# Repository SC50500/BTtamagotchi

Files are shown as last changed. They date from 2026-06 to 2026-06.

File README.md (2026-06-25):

# ARIRANG
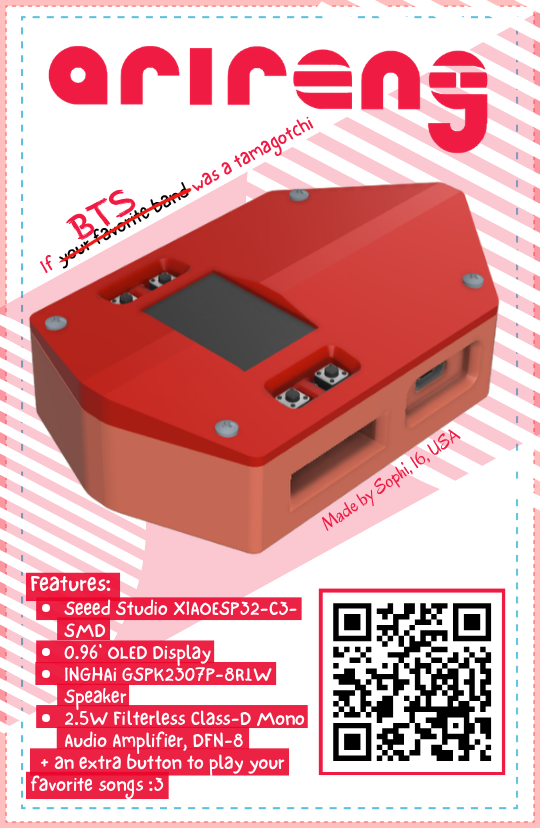
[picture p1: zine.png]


# Description
A 4-button tamagotchi remix based on global pop band BTS's new album "ARIRANG" featuring a speaker in place of a buzzer and unique tamagotchi dancing emoticons. Instead of indicating changes in the pet's state using buzzes, the ARIRANG tamagotchi uses a sequence of notes from the speaker to play a familiar tune. What makes this tamagotchi design unique is that it uses easily accessible parts and produces sound from the speaker without storage of music on a micro-SD card or similar component. Music is played through using the tone() function in the Arduino IDE. 

# Purpose
The basic eat, sleep, and play functions of your average tamagotchi are still present in this design, allowing users to interact with their tamagotchi pet at any time of day. An additional music feature has been added to the tamagotchi, as coded for by the fourth button on the PCB. This button plays one of three tunes, extrapolated from popular BTS songs and inspired by piano or music box covers arranged by other composers and artists (View credits for more information). 

For more information about what a tamagotchi is and how to use it, check out [this guide](https://tamagotchi.fandom.com/wiki/Main_Page) on what a tamagotchi is. 

# Inspiration
As someone who has been a fan of BTS since they were 7 years old, I've dreamed of completing a project that allowed me to take creative liberty in designing a product that reflected both my interest in KPOP and engineering.
The theme of the tamagotchi was centered around "ARIRANG", BTS's newest album that was recently released this year. After being inactive as a band for over 3 years, this was the long-awaited "comeback" album that myself and other long-time fans were excited to listen to.
More importantly, this album holds a different meaning to the fandom, ARMY, and the group; It is meant to represent a return to the roots from which BTS first came.
So, in honor of their return from their hiatus, I decided to dedicate my first hardware project to them -- A band whose songs motivated me throughout all of the obstacles I overcame to ship this project. 

# Features
* **0.96" OLED Display (128 x 64):** Black and white, yes, but perfect for Van, a character that is monochromatic ;3
* **INGHAi Speaker:** A small, but powerful speaker with a simple adapter that allows for music from Arduino IDE or bluetooth to be played. 
* **Four tactile switches:** The first three are for the basic eat, sleep, and play functions of the tamagotchi, but the fourth is a "music" button that activates one of three tunes that any BTS fan would recognize, paired with a pet dancing animation.
* **Unique themed pet and animations:** Your tamagotchi pet goes by the name Van! Van is a character from the LINE x BTS collaboration, which produced a line of BTS mascots called BT21. In this collaboration, Van represents the ARMY, BTS's fandom, instead of a specific member. I felt that because of this, Van was the most suitable mascot for this project. 

# How does this work? 
Each of the four different buttons are mapped to one of four screens: eat, play, sleep, and dance/music.

* Left-up button: For when Van is feeling a bit peckish
* Left-down button: For when Van is bored
* Right-up button: For when Van needs some rest
* Right-down button: For when Van is ready to party :3

When these buttons are pressed, a quick transition music is played to indicate a change in Van's status. If any of Van's status bars (Hunger, Happiness, and Energy) fall below 50, Van's expression will change into a sad expression. 

After each animation runs its course, the screen returns back to the main screen while the pet awaits further instruction.

# Design
Below are all of the screenshots of my design (plus screenshots by layer and an exploded view :3)










# Bill of Materials

| Item | Unit Price | Quantity Used | Quantity Purchased | Total Price | Source | Notes |
|---|---|---|---|---|---|---|
| Seeed Studio XIAO ESP32-C3 | $9.90 | 1 | 1 | $9.90 | [Link](https://www.amazon.com/dp/B0B94JZ2YF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) | purchased with other items off Amazon; free shipping |
| HS96L03W2C03 | $2.24 | 1 | 1 | $2.24 | [Link](https://www.lcsc.com/product-detail/C5248080.html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) | shipping not included |
| INGHAi GSPK2307P-8R1W | $0.82 | 1 | 1 | $0.82 | [Link](https://www.lcsc.com/product-detail/Speakers_INGHAi-GSPK2307P-8R1W_C530531.html) | shipping not included |
| PAM8302AAYCR | $9.37 | 1 | 1 | $9.37 | [Link](https://www.digikey.com/en/products/detail/diodes-incorporated/PAM8302AAYCR/4033367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) | shipping included |
| BZCN TSC016A04518A | $0.04 | 4 | 50 | $0.54 | [Link](https://www.lcsc.com/product-detail/C2888493.html?s_z=h_q_C2888493&globalKeyword=C2888493) | shipping not included |
| UNIT 502030 D9 - 250mAh 3.7V 0.93Wh | $8.99 | 1 | 1 | $8.99 | [Link](https://www.amazon.com/dp/B08FD3V6TF?lv=shuf&channelId=520&plpRedirect=mhFallback) | shipping not included |
| TAMAGOTCHI PCB | $2.00 | 1 | 5 | $2.00 | [Link](https://cart.jlcpcb.com/shopcart/cart/) | first PCB is $2.00; no shipping fee or taxes (Global standard line) |
| M3 x 8mm Pozi Pan Head Screws | $0.09 | 2 | 20 | $0.99 | [Link](https://www.aliexpress.us/item/3256807955659503.html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) | not 1:1 to the attached CAD; but can still be used; shipping not included |
| M2 x 8mm Pozi Pan Head Screws | $0.20 | 4 | 20 | $0.99 | [Link](https://www.aliexpress.us/item/3256807955659503.html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) | not 1:1 to the attached CAD; but can still be used; shipping not included |
| *AMAZON SHIPPING & TAXES* |  |  |  | *$9.29* |  | ONLY shipping fees and taxes for all products purchased through Amazon |
| *LCSC SHIPPING & TAXES* |  |  |  | *$10.65* |  | ONLY shipping fees and taxes for all products purchased through LCSC |
| *ALIEXPRESS SHIPPING & TAXES* |  |  |  | *$4.09* |  | ONLY shipping fees and taxes for all products purchased through AliExpress |
| **TOTAL** |  |  |  | **$53.80** |  |  |

# Build & Assembly

## Required Tools

- Soldering iron
- Solder
- Tweezers
- Small screwdriver for M3 screws
- Computer with USB port
- 3D printer

## Assembly Steps

1. Solder all the THT diodes onto the PCB
2. Solder the LEDs to the PCB. I rotated the direction of the bottom row by accident so refer to the PCB layout if the orientation is confusing at all
3. Solder the microcontroller, OLED display, and switches to the PCB
4. To assemble the case, place the PCB into the bottom shell
5. Attach it to the top shell
6. Secure with M3 screws.
7. Since this build uses the ESP32-C3, I will use the ESPRESSIF Arduino IDE Extension to install firmware
8. Plug in the ESP32-C3 to your computer with a USB cable
9. Select the correct board and port in the Arduino IDE, then upload the firmware
10. Modify the code if you'd like to change Van's animations or tune selection
11. Test your OLED (check I2C, SDA/SCL pins, etc) and your speaker
12. Once everything works, you will have a fully functional Van!

# Credits & Acknowledgements

Credits to BTS's new "ARIRANG" album cover and the BTS ARMY Logo for the hardware design inspiration. 

## Libraries & Extensions Used

Libraries and extensions used in firmware
* ESPRESSIF Arduino IDE Extension
* Adafruit SSD1306
* Adafruit GFX Library

## Music Attribution & Copyright Disclaimer
The audio files included in this repository are piano covers intended for non-commercial entertainment purposes only.

*    *Original Composition:* "Crystal Snow", "Spring Day", and "Butterfly", intitially performed by BTS, copyrighted by Big Hit Music / HYBE. 
*    *Arrangements:* Based on the piano arrangements by [SMYANG PIANO](https://www.youtube.com/c/smyangpiano) (used with pending permission.
*    *Performances:* Recorded and arranged by Sophia Chan.

*Disclaimer: Although the music used in the tamagotchi are inspired by the music box and piano arrangements created by SMYANG PIANO as a cover for BTS's music, the actual arrangements slightly differ in composition.*

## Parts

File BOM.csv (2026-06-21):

Item | Unit Price | Quantity Used | Quantity Purchased | Total Price | Source | Notes
Seeed Studio XIAO ESP32-C3 | $9.90 | 1 | 1 | $9.90 | https://www.amazon.com/dp/B0B94JZ2YF?lv=shuf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 | purchased with other items off Amazon; free shipping
HS96L03W2C03 | $2.24 | 1 | 1 | $2.24 | https://www.lcsc.com/product-detail/C5248080.html | shipping not included
INGHAi GSPK2307P-8R1W | $0.82 | 1 | 1 | $0.82 | https://www.lcsc.com/product-detail/Speakers_INGHAi-GSPK2307P-8R1W_C530531.html | shipping not included
PAM8302AAYCR | $9.37 | 1 | 1 | $9.37 | https://www.digikey.com/en/products/detail/diodes-incorporated/PAM8302AAYCR/4033367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 | shipping included
BZCN TSC016A04518A | $0.04 | 4 | 50 | $0.54 | https://www.lcsc.com/product-detail/C2888493.html?s_z=h_q_C2888493&globalKeyword=C2888493 | shipping not included
UNIT 502030 D9 - 250mAh 3.7V 0.93Wh | $8.99 | 1 | 1 | $8.99 | https://www.amazon.com/dp/B08FD3V6TF?lv=shuf&channelId=520&plpRedirect=mhFallback | shipping not included
TAMAGOTCHI PCB | $2.00 | 1 | 5 | $2.00 | https://cart.jlcpcb.com/shopcart/cart/ | first PCB is $2.00; no shipping fee or taxes (Global standard line)
M3 x 8mm Pozi Pan Head Screws | $0.09 | 2 | 20 | $0.99 | https://www.aliexpress.us/item/3256807955659503.html?curPageLogUid=W6HOdQGM0dw9 | not 1:1 to the attached CAD; but can still be used; shipping not included
M2 x 8mm Pozi Pan Head Screws | $0.20 | 4 | 20 | $0.99 | https://www.aliexpress.us/item/3256807955659503.html?curPageLogUid=W6HOdQGM0dw9 | not 1:1 to the attached CAD; but can still be used; shipping not included
AMAZON SHIPPING & TAXES |  |  |  | $9.29 |  | ONLY shipping fees and taxes for all products purchased through Amazon
LCSC SHIPPING & TAXES |  |  |  | $10.65 |  | ONLY shipping fees and taxes for all products purchased through LCSC
ALIEXPRESS SHIPPING $ TAXES |  |  |  | $4.09 |  | ONLY shipping fees and taxes for all products purchased through AliExpress
TOTAL |  |  |  | $59.87

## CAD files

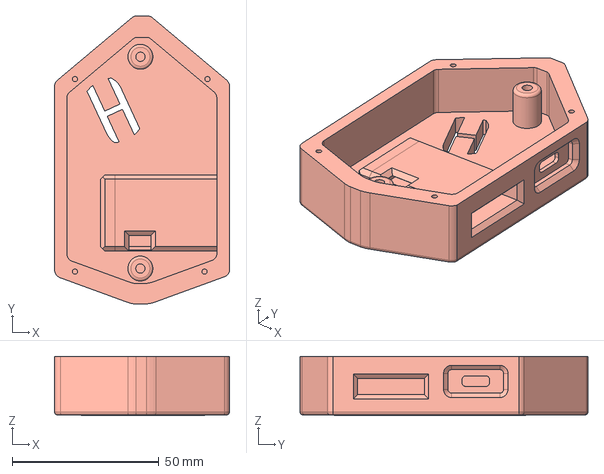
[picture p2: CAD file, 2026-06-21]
case/CAD files/Top.step
59.7 x 98.2 x 20.3 mm

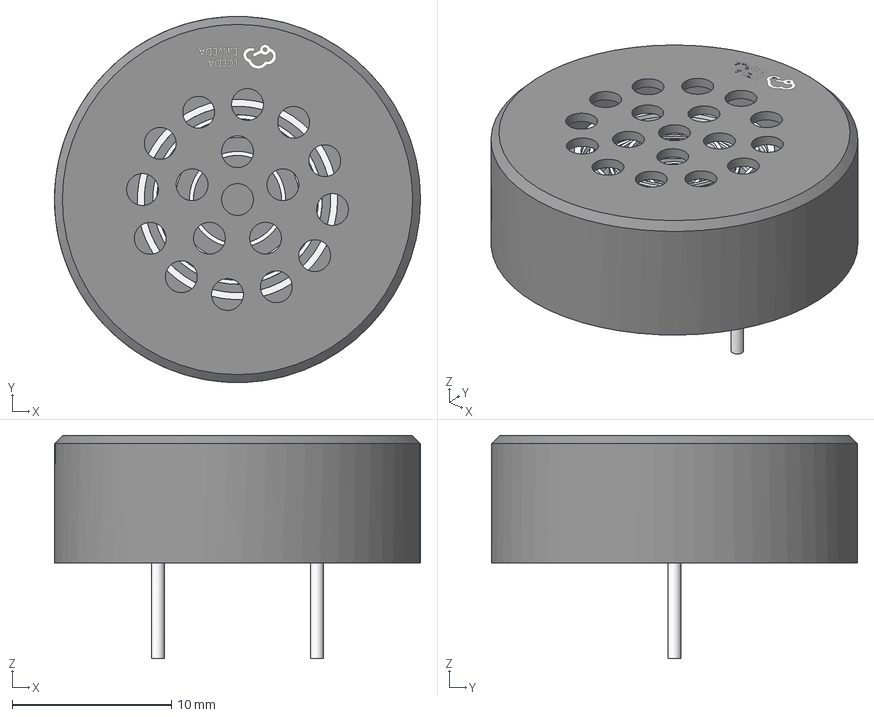
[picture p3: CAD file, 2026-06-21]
case/CAD models/SPK-TH_BD23.0-P10.00-D0.8-L-RD.step
23.0 x 23.0 x 14.0 mm
SPK-TH_BD2 x 21

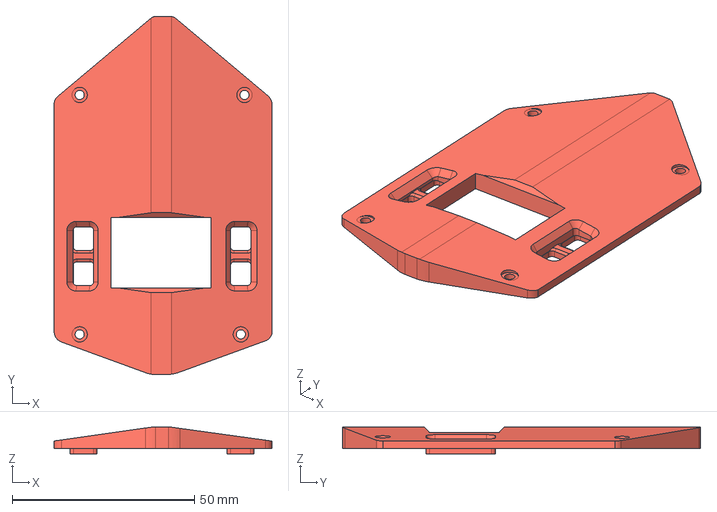
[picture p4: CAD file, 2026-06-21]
case/CAD files/Bottom.step
59.7 x 98.1 x 7.30 mm

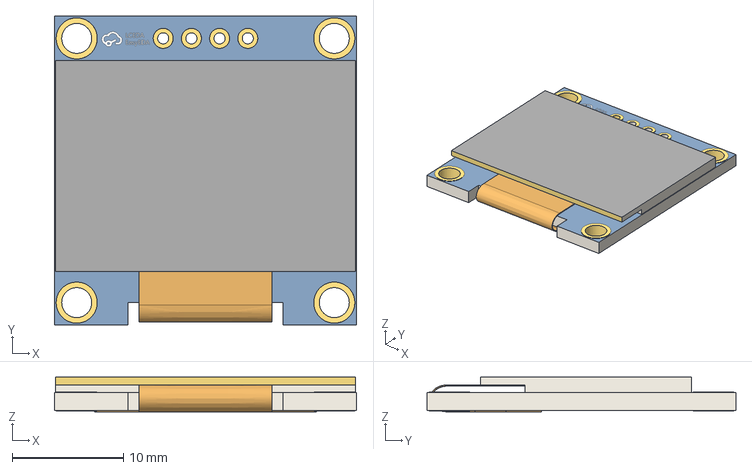
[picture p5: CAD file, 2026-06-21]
case/CAD models/OLED-TH_L27.8-W27.2-P2.54_C9900033791.step
27.2 x 27.8 x 3.12 mm

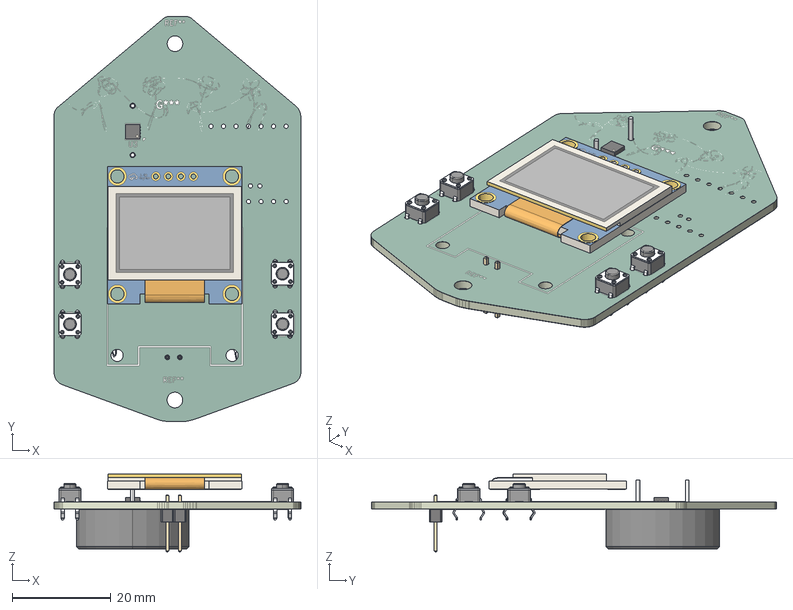
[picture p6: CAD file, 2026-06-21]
case/CAD files/ARIRANG.step
50.0 x 82.0 x 15.7 mm
DFN-8-1EP_3x3mm_Pitch0.65mm
OLED-TH_L27.8-W27.2-P2.54_C9900033791
PinHeader_1x02_P254mm_Vertical
SPK-TH_BD2
BTtamagotchi_copper
BTtamagotchi_via
BTtamagotchi_silkscreen x 2
BTtamagotchi_soldermask x 2
BTtamagotchi_PCB

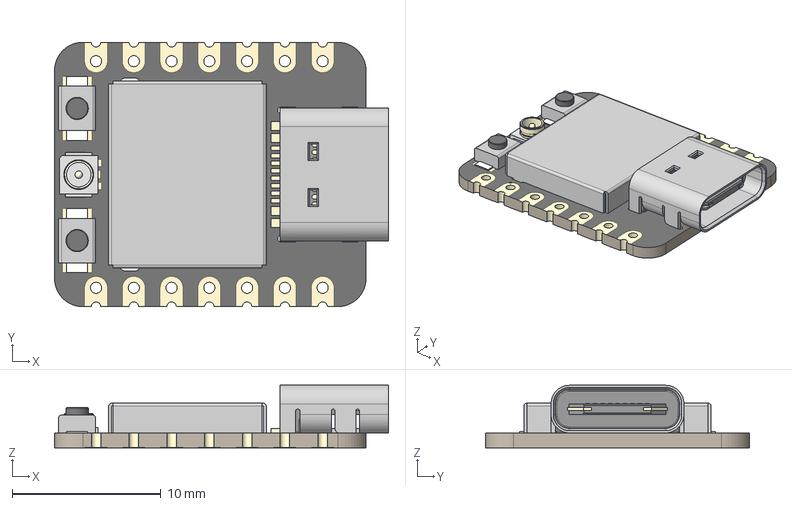
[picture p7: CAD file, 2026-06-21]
case/CAD models/Seeed Studio XIAO-ESP32-C3 v15.step
22.5 x 17.8 x 4.21 mm
U.FL Connector v1 x 3
Shield
Button (1) x 2
Seeed Studio XIAO-ESP32-C3 v15
MIRROR2
BOSS-EXTRUDE7_3_
BOSS-EXTRUDE14_9_
BOSS-EXTRUDE7_9_
CUT-EXTRUDE5
BOSS-EXTRUDE14_6_
BOSS-EXTRUDE14_4_
BOSS-EXTRUDE7_1_
BOSS-EXTRUDE14_5_
BOSS-EXTRUDE14_10_
BOSS-EXTRUDE14_11_
BOSS-EXTRUDE7_8_
BOSS-EXTRUDE14_1_
BOSS-EXTRUDE14_8_
BOSS-EXTRUDE7_6_
BOSS-EXTRUDE7_4_
BOSS-EXTRUDE7_7_
BOSS-EXTRUDE14_7_
BOSS-EXTRUDE14_12_
BOSS-EXTRUDE14_3_
BOSS-EXTRUDE7_2_
BOSS-EXTRUDE14_2_
BOSS-EXTRUDE7_5_

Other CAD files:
case/CAD files/ARIRANG FINAL.f3d
case/CAD files/Bottom.stl
case/CAD files/Top.stl

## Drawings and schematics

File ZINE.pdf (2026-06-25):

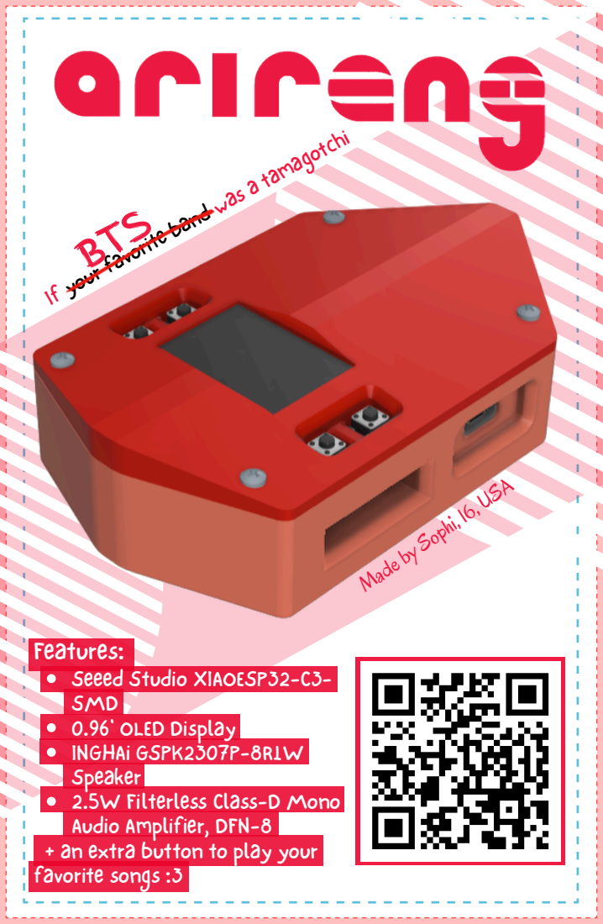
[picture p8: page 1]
BTS; Features:; 0.96' OLED Display INGHAi GSPK2307P-8R1W; USA

If your favorite band was a tamagotchi

Made by Sophi,

Seeed Studio XIAOESP32-C3-
SMD
Speaker
2.5W Filterless Class-D Mono
Audio Amplifier, DFN-8

+ an extra button to play your
favorite songs :3

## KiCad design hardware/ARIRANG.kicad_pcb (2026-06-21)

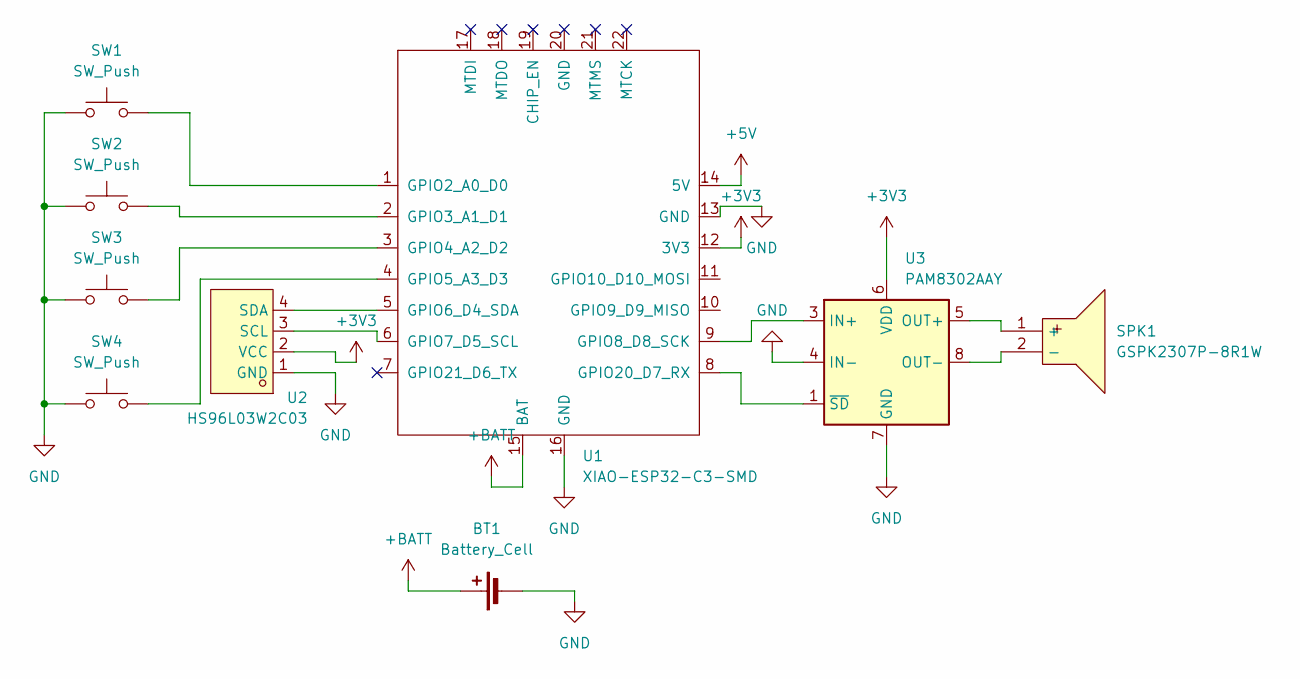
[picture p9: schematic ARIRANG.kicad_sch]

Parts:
BT1: Battery_Cell; PinHeader_1x02_P2.54mm_Vertical
SPK1: GSPK2307P-8R1W; SPK-TH_BD23.0-P10.00-D0.8-L-RD; MPN GSPK2307P-8R1W; LCSC Part C530531
SW1, SW2, SW3, SW4: SW_Push; SW-TH_4P-L4.5-W4.5-P3.00-LS4.8
U1: XIAO-ESP32-C3-SMD; XIAO-ESP32-C3-DIP-SMD
U2: HS96L03W2C03; OLED-TH_L27.8-W27.2-P2.54_C9900033791; MPN HS96L03W2C03; LCSC Part C5248080
U3: PAM8302AAY; DFN-8-1EP_3x3mm_P0.65mm_EP1.55x2.4mm

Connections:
+3V3: U1.12 (3V3), U2.2 (VCC), U3.6 (VDD)
+5V: U1.14 (5V)
+BATT: BT1.1 (+), U1.15 (BAT)
GND: BT1.2 (-), SW1.1, SW2.1, SW3.1, SW4.1, U1.13 (GND), U1.16 (GND), U2.1 (GND), U3.4 (IN-), U3.7 (GND)
unnamed: SPK1.1 (+), U3.5 (OUT+)
unnamed: SPK1.2 (-), U3.8 (OUT-)
unnamed: SW1.2, U1.1 (GPIO2_A0_D0)
unnamed: SW2.2, U1.2 (GPIO3_A1_D1)
unnamed: SW3.2, U1.3 (GPIO4_A2_D2)
unnamed: SW4.2, U1.4 (GPIO5_A3_D3)
unnamed: U1.5 (GPIO6_D4_SDA), U2.4 (SDA)
unnamed: U1.6 (GPIO7_D5_SCL), U2.3 (SCL)
unnamed: U1.9 (GPIO8_D8_SCK), U3.3 (IN+)
unnamed: U1.8 (GPIO20_D7_RX), U3.1 (~SD)

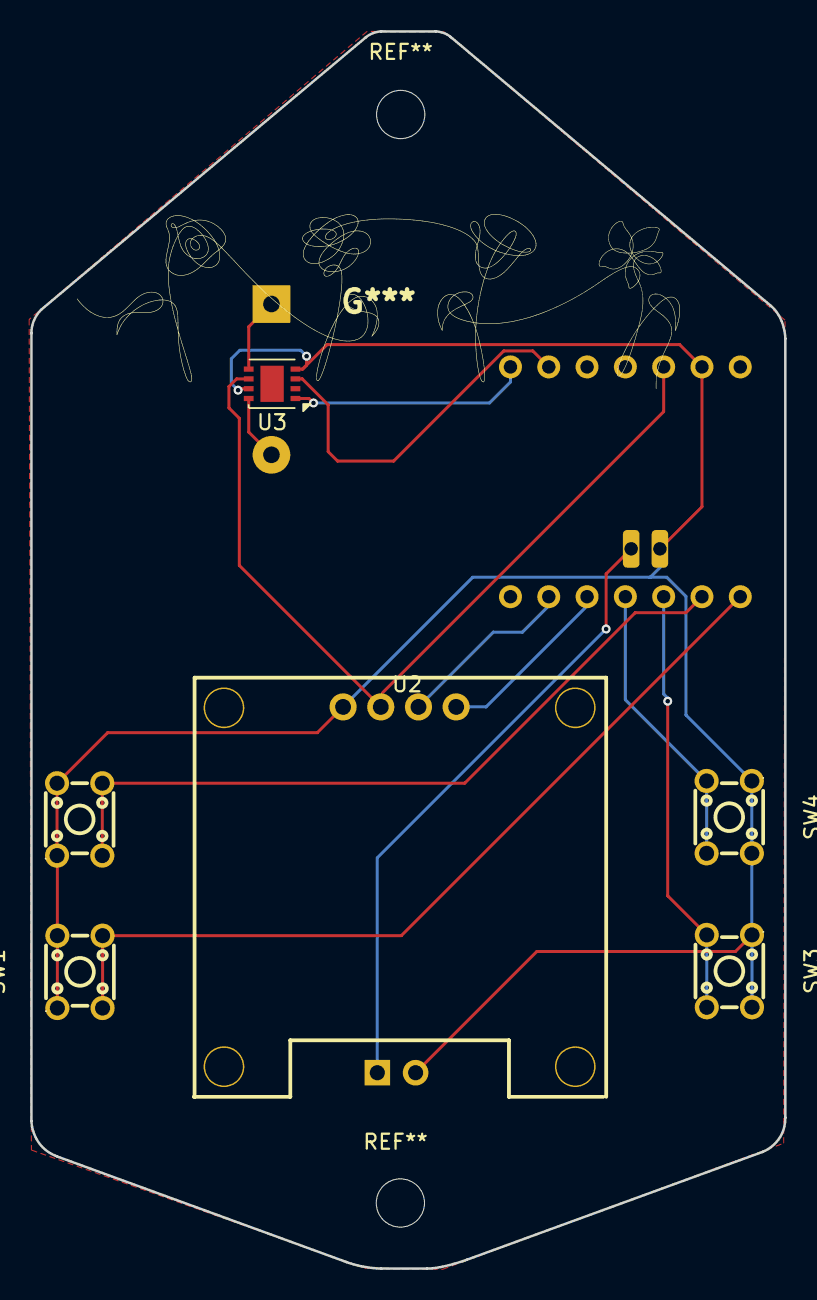
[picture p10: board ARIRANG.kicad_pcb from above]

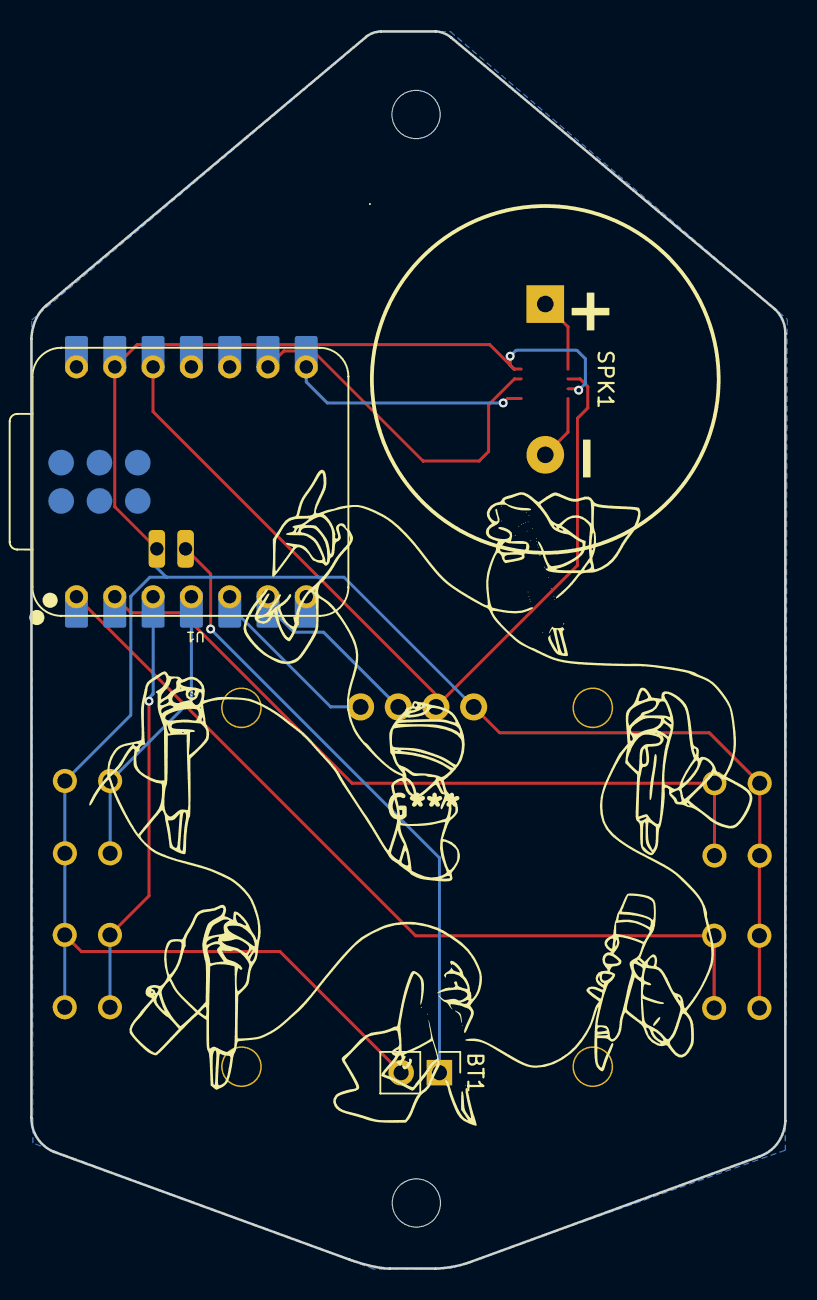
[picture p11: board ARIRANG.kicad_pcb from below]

Board: 2 copper layers, 50.0 x 82.0 mm, 9 parts (3 on the bottom side), 13 nets.

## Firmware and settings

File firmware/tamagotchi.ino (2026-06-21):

//Buttons (traced from schematic)
#define BTN1 0
#define BTN2 1
#define BTN3 2
#define BTN4 3
//OLED (traced from schematic)
#define SDA_PIN 5
#define SCL_PIN 6
//Speaker (traced from schematic)
#define SD_PIN 20
#define IN_PIN 8

#include <Wire.h>
#include <Adafruit_GFX.h>
#include <Adafruit_SSD1306.h>

#define SCREEN_WIDTH 128
#define SCREEN_HEIGHT 64
#define OLED_RESET -1

Adafruit_SSD1306 display(SCREEN_WIDTH, SCREEN_HEIGHT, &Wire, OLED_RESET);

#define BTN_LEFTUP   D0
#define BTN_LEFTDWN  D1
#define BTN_RIGHTUP  D2
#define BTN_RIGHTDWN D3
#define SPK_SD D7
#define SPK_IN D8

struct Member {
  int hunger;
  int happiness;
  int energy;
  unsigned long age;
}

Member Jimin;

enum Screen{
  SCREEN_MAIN,
  SCREEN_FEED,
  SCREEN_PLAY,
  SCREEN_SLEEP,
  SCREEN_MUSIC,
}

#define b3f 233 // 233 Hz
#define b3  247 // 247 Hz
#define e4f 311 // 311 Hz
#define g4  392 // 392 Hz
#define b4f 466 // 466 Hz
#define b4  493 // 493 Hz
#define c5s 554 // 554 Hz
#define d5  587 // 587 Hz
#define e5f 622 // 622 Hz
#define f5  698 // 698 Hz
#define g5  784 // 784 Hz
#define a5f 831 // 831 Hz
#define b5f 932 // 932 Hz

#define BUZZER_PIN 8  // change to match your wiring

// ---------- Garage_Band.mp3 ----------
const int GarageBand_notes[] = {
  b4f, a5f, g5, g4, g5, g4, g4, g4, g4, g4, f5, f5, g5, b4f, g5, g4, g4, g4,
  g4, g4, f5, f5, g5, g4, g4, g4, e5f, e4f, f5, d5, d5, b4f, b4f, b3f, d5,
  e5f, f5, f5, e5f, e4f, b4, b4, b4, b4f, b3f
};
const int GarageBand_durations[] = {
  615, 708, 789, 499, 708, 627, 372, 337, 290, 337, 372, 627, 1556, 279, 372,
  627, 337, 372, 290, 337, 372, 1126, 337, 372, 290, 383, 325, 964, 372, 1126,
  383, 337, 325, 337, 325, 998, 337, 998, 337, 1010, 325, 998, 337, 1115, 343
};
const int GarageBand_length = sizeof(GarageBand_notes) / sizeof(GarageBand_notes[0]);

// ---------- butterfly.mp3 ----------
const int Butterfly_notes[] = {
  c5s, c5s, e5f, e5f, e5f, e5f, e5f, e5f, c5s, c5s, e5f, e5f, e5f, c5s, c5s,
  e5f, e5f, e5f, e5f, e5f, e5f, c5s, f5, e5f, e5f, f5, e5f, e5f, e5f, c5s,
  e5f, c5s, f5, c5s, c5s, b5f
};
const int Butterfly_durations[] = {
  313, 313, 313, 325, 313, 313, 313, 313, 325, 859, 313, 313, 720, 313, 313,
  325, 313, 313, 313, 313, 325, 313, 313, 1498, 708, 325, 1254, 1428, 313,
  313, 313, 325, 627, 313, 313, 1489
};
const int Butterfly_length = sizeof(Butterfly_notes) / sizeof(Butterfly_notes[0]);

// ---------- crystal_snow.mp3 ----------
const int CrystalSnow_notes[] = {
  e5f, b5f, e5f, d5, b5f, b4f, e5f, b5f, f5, b5f, f5, g5, b5f, g5, g5, b4f,
  e5f, b5f, e5f, d5, b5f, b4f, e5f, b5f, f5, b4f, f5, g5, b5f, g5, b5f, b5f,
  b5f
};
const int CrystalSnow_durations[] = {
  325, 313, 313, 325, 313, 313, 313, 325, 313, 313, 313, 313, 325, 313, 313,
  313, 313, 325, 313, 313, 313, 313, 313, 325, 313, 313, 313, 313, 325, 313,
  859, 313, 305
};
const int CrystalSnow_length = sizeof(CrystalSnow_notes) / sizeof(CrystalSnow_notes[0]);

// Playback helper
void playMelody(const int notes[], const int durations[], int length) {
  for (int i = 0; i < length; i++) {
    int noteDuration = durations[i];
    tone(BUZZER_PIN, notes[i], noteDuration);
    // pause between notes ~10% of the note's length, for separation
    int pauseBetween = noteDuration * 1.10;
    delay(pauseBetween);
    noTone(BUZZER_PIN);
  }
}

// Named functions, one per source file
void playGarageBand() {
  playMelody(GarageBand_notes, GarageBand_durations, GarageBand_length);
}

void playButterfly() {
  playMelody(Butterfly_notes, Butterfly_durations, Butterfly_length);
}

void playCrystalSnow() {
  playMelody(CrystalSnow_notes, CrystalSnow_durations, CrystalSnow_length);
}

Screen currentScreen = SCREEN_MAIN;

void setup() {
  // put your setup code here, to run once:
  pinMode(BTN_LEFTUP, INPUT_PULLUP);
  pinMode(BTN_LEFTDWN, INPUT_PULLUP);
  pinMode(BTN_RIGHTUP, INPUT_PULLUP);
  pinMode(BTN_RIGHTUP, INPUT_PULLUP);
  pinMode(SPK_SD, INPUT_PULLUP);
  pinMode(SPK_IN, OUTPUT);

  display.begin(SSD1306_SWITCHCAPVCC, 0x3C);
  display.clearDisplay();
  display.setTextSize(1);
  display.setTextColor(SSD1306_WHITE);
  display.setCursor(0,0);
  display.println("Tamagotchi Init...");
  display.display();
  delay(1000);

  member.hunger = 80;
  member.happiness = 80;
  member.energy = 80;
  member.age = 0;
}

unsigned long lastUpdate = 0;

void updatePet(){
  if(millis() - lastUpdate > 5000){
    pet.hunger--;
    pet.happiness--;
    pet.energy--;
    
    if(pet.hunger < 0) pet.hunger = 0;
    if(pet.happiness < 0) pet.happiness = 0;
    if(pet.energy < 0) pet.energy = 0;
    
    pet.age +=== 5;
    lastUpdate = millis();
  }
}

unsigned long lastButtonPress = 0;
int 

void checkButtons(){
  if(millis() - lastButtonPress < 200) return;
  
  if(digitalRead(BTN_LEFTUP) == LOW){
    currentScreen = SCREEN_FEED;
    tone(SPK_IN, 1000, 50);
    lastButtonPress = millis();
  }
  else if(digitalRead(BTN_LEFTDWN) == LOW){
    currentScreen = SCREEN_PLAY;
    tone(SPK_IN, 1000, 50);
    lastButtonPress = millis();
  }
  else if(digitalRead(BTN_RIGHTUP) == LOW){
    currentScreen = SCREEN_SLEEP;
    tone(SPK_IN, 1000, 50);
    lastButtonPress = millis();
  }
  else(digitalRead(BTN_RIGHTDWN) == LOW){
    currentScreen = SCREEN_MUSIC;
    tone(SPK_IN, 1000, 50);
    lastButtonPress = millis();
  }
}

void handleScreenLogic(){
  switch(currentScreen){
    case SCREEN_FEED:
      pet.hunger += 10;
      if(pet.hunger > 100) pet.hunger = 100;
      currentScreen = SCREEN_MAIN;
      break;
    
    case SCREEN_PLAY:
      pet.happiness += 10;
      pet.energy -= 5;
      if(pet.happiness > 100) pet.happiness = 100;
      if(pet.energy < 0) pet.energy = 0;
      currentScreen = SCREEN_MAIN;
      break;

    case SCREEN_SLEEP:
      pet.energy += 5;
      if(pet.energy > 100) pet.energy = 100;
      currentScreen = SCREEN_MAIN;
      break;

    case SCREEN_MUSIC:
      pet.happiness += 5;
      pet.energy -= 2;
      if(pet.happiness > 100) pet.happiness = 100;
      if(pet.energy < 0) pet.energy = 0;
      currentScreen = SCREEN_MAIN;
      playGarageBand();
      playButterfly();
      playCrystalSnow();
      break;
    
    case SCREEN_MAIN:
      break;
  }
}

#include <Arduino.h>

const unsigned char PROGMEM frame0[] = {
  0b00000000, 0b00000000, 0b00000000, 0b00000000, 0b00000000, 0b00000000, 0b00000000, 0b00000000, 0b00000000, 0b00000000,
  0b00000000, 0b00000000, 0b00000011, 0b11000000, 0b00000000, 0b00000000, 0b00000000, 0b00000000, 0b00000000, 0b00000000,
  0b00000000, 0b00000000, 0b00000010, 0b01000000, 0b00000000, 0b00000000, 0b00000000, 0b00000000, 0b00000000, 0b00000000,
  0b00000000, 0b00000000, 0b00000110, 0b10100000, 0b00000000, 0b00000000, 0b00000000, 0b00000000, 0b00000000, 0b00000000,
  0b00000000, 0b00000000, 0b00000101, 0b10100000, 0b00000000, 0b00000000, 0b00000000, 0b00000000, 0b00000000, 0b00000000,
  0b00000000, 0b00000000, 0b00001101, 0b10010000, 0b00000000, 0b00000000, 0b00000000, 0b00000000, 0b00000000, 0b00000000,
  0b00000000, 0b00000000, 0b00001001, 0b11010000, 0b00000000, 0b00000000, 0b00000000, 0b00000000, 0b00000000, 0b00000000,
  0b00000000, 0b00000000, 0b00011001, 0b11101000, 0b00000000, 0b00000000, 0b00000000, 0b00000000, 0b00000000, 0b00000000,
  0b00000000, 0b00000000, 0b00010001, 0b11101000, 0b00000000, 0b00000000, 0b00000000, 0b00000000, 0b00000000, 0b00000000,
  0b00000000, 0b00000000, 0b00110001, 0b11110100, 0b00000000, 0b00000000, 0b00000000, 0b00000000, 0b00000000, 0b00000000,
  0b00000000, 0b00000000, 0b01100001, 0b11110010, 0b00000000, 0b00000000, 0b00000000, 0b00000000, 0b00000000, 0b00000000,
  0b00000000, 0b00000001, 0b11000001, 0b11111101, 0b10000000, 0b00000000, 0b00000000, 0b00000000, 0b00000000, 0b00000000,
  0b00000000, 0b00001111, 0b00000001, 0b11111100, 0b01110000, 0b00000000, 0b00000000, 0b00000000, 0b00000000, 0b00000000,
  0b00000000, 0b00011000, 0b00000001, 0b11111111, 0b10001000, 0b00000000, 0b00000000, 0b00000000, 0b00000000, 0b00000000,
  0b00000000, 0b01100000, 0b00000001, 0b11111111, 0b11110110, 0b00000000, 0b00000000, 0b00000000, 0b00000000, 0b00000000,
  0b00000000, 0b11000000, 0b00000001, 0b11111111, 0b11111001, 0b00000000, 0b00000000, 0b00000000, 0b00000000, 0b00000000,
  0b00000001, 0b10000000, 0b00000001, 0b11111111, 0b11111110, 0b10000000, 0b00000000, 0b00000000, 0b00000000, 0b00000000,
  0b00000011, 0b00000000, 0b00000001, 0b11111111, 0b11111111, 0b01000000, 0b00000000, 0b00000000, 0b00000000, 0b00000000,
  0b00000010, 0b00000000, 0b00000001, 0b11111111, 0b11111111, 0b01000000, 0b00000000, 0b00000000, 0b00000000, 0b00000000,
  0b00000100, 0b00000000, 0b00000001, 0b11111111, 0b11111111, 0b10100000, 0b00000000, 0b00000000, 0b00000000, 0b00000000,
  0b00001000, 0b00000000, 0b00000001, 0b11111111, 0b11111111, 0b11010000, 0b00000000, 0b00000000, 0b00000000, 0b00000000,
  0b00001000, 0b00000000, 0b00000001, 0b11111111, 0b11111111, 0b11010000, 0b00000000, 0b00000000, 0b00000000, 0b00000000,
  0b00010000, 0b00000000, 0b00000001, 0b11111111, 0b11111111, 0b11101000, 0b00000000, 0b00000000, 0b00000000, 0b00000000,
  0b00010000, 0b00000000, 0b00000001, 0b11111111, 0b11111111, 0b11101000, 0b00000000, 0b00000000, 0b00000000, 0b00000000,
  0b00100000, 0b00000000, 0b00000001, 0b11111111, 0b11111111, 0b11110100, 0b00000000, 0b00000000, 0b00000000, 0b00000000,
  0b00100000, 0b00000000, 0b00000001, 0b11111111, 0b11111111, 0b11110100, 0b00000000, 0b00000000, 0b00000000, 0b00000000,
  0b00100000, 0b00000000, 0b00000001, 0b11111111, 0b11111111, 0b11110100, 0b00000000, 0b00000000, 0b00000000, 0b00000000,
  0b01000000, 0b00000000, 0b00000001, 0b11111111, 0b11111111, 0b11111010, 0b00000000, 0b00000000, 0b00000000, 0b00000000,
  0b01000000, 0b00000000, 0b00000001, 0b11111111, 0b11111111, 0b11111010, 0b00000000, 0b00000000, 0b00000000, 0b00000000,
  0b01000000, 0b00000000, 0b00000001, 0b11111111, 0b11111111, 0b11111010, 0b00000000, 0b00000000, 0b00000000, 0b00000000,
  0b01000000, 0b00000000, 0b00000001, 0b11111111, 0b11111111, 0b11111010, 0b00000000, 0b00000000, 0b00000000, 0b00000000,
  0b01000000, 0b00011000, 0b01100001, 0b11111110, 0b00111111, 0b11111010, 0b00000000, 0b00000000, 0b00000000, 0b00000000,
  0b01000000, 0b00001100, 0b11000001, 0b11111101, 0b11011111, 0b11111010, 0b00000000, 0b00000000, 0b00000000, 0b00000000,
  0b01000000, 0b00000111, 0b10000001, 0b11111011, 0b11101111, 0b11111010, 0b00000000, 0b00000000, 0b00000000, 0b00000000,
  0b01000000, 0b00000011, 0b00000001, 0b11111011, 0b11101111, 0b11111010, 0b00000000, 0b00000000, 0b00000000, 0b00000000,
  0b01000000, 0b00000111, 0b10000001, 0b11111011, 0b11101111, 0b11111010, 0b00000000, 0b00000000, 0b00000000, 0b00000000,
  0b01100000, 0b00001100, 0b11000001, 0b11111101, 0b11011111, 0b11111010, 0b00000000, 0b00000000, 0b00000000, 0b00000000,
  0b00100000, 0b00011000, 0b01100001, 0b11111110, 0b00111111, 0b11111010, 0b00000000, 0b00000000, 0b00000000, 0b00000000,
  0b00100000, 0b00000000, 0b00000001, 0b11111111, 0b11111111, 0b11110100, 0b00000000, 0b00000000, 0b00000000, 0b00000000,
  0b00110000, 0b00000000, 0b00000001, 0b11111111, 0b11111111, 0b11110100, 0b00000000, 0b00000000, 0b00000000, 0b00000000,
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
};

const unsigned char PROGMEM frame1[] = {
  0b00000000, 0b00000000, 0b00000000, 0b00000000, 0b00000000, 0b00000000, 0b00000000, 0b00000000, 0b00000000, 0b00000000,
  0b00000000, 0b00000000, 0b00000011, 0b11000000, 0b00000000, 0b00000000, 0b00000000, 0b00000000, 0b00000000, 0b00000000,
  0b00000000, 0b00000000, 0b00000010, 0b01000000, 0b00000000, 0b00000000, 0b00000000, 0b00000000, 0b00000000, 0b00000000,
  0b00000000, 0b00000000, 0b00000110, 0b10100000, 0b00000000, 0b00000000, 0b00000000, 0b00000000, 0b00000000, 0b00000000,
  0b00000000, 0b00000000, 0b00000101, 0b10100000, 0b00000000, 0b00000000, 0b00000000, 0b00000000, 0b00000000, 0b00000000,
  0b00000000, 0b00000000, 0b00001101, 0b10010000, 0b00000000, 0b00000000, 0b00000000, 0b00000000, 0b00000000, 0b00000000,
  0b00000000, 0b00000000, 0b00001001, 0b11010000, 0b00000000, 0b00000000, 0b00000000, 0b00000000, 0b00000000, 0b00000000,
  0b00000000, 0b00000000, 0b00011001, 0b11101000, 0b00000000, 0b00000000, 0b00000000, 0b00000000, 0b00000000, 0b00000000,
  0b00000000, 0b00000000, 0b00010001, 0b11101000, 0b00000000, 0b00000000, 0b00000000, 0b00000000, 0b00000000, 0b00000000,
  0b00000000, 0b00000000, 0b00110001, 0b11110100, 0b00000000, 0b00000000, 0b00000000, 0b00000000, 0b00000000, 0b00000000,
  0b00000000, 0b00000000, 0b01100001, 0b11110010, 0b00000000, 0b00000000, 0b00000000, 0b00000000, 0b00000000, 0b00000000,
  0b00000000, 0b00000001, 0b11000001, 0b11111101, 0b10000000, 0b00000000, 0b00000000, 0b00000000, 0b00000000, 0b00000000,
  0b00000000, 0b00001111, 0b00000001, 0b11111100, 0b01110000, 0b00000000, 0b00000000, 0b00000000, 0b00000000, 0b00000000,
  0b00000000, 0b00011000, 0b00000001, 0b11111111, 0b10001000, 0b00000000, 0b00000000, 0b00000000, 0b00000000, 0b00000000,
  0b00000000, 0b01100000, 0b00000001, 0b11111111, 0b11110110, 0b00000000, 0b00000000, 0b00000000, 0b00000000, 0b00000000,
  0b00000000, 0b11000000, 0b00000001, 0b11111111, 0b11111001, 0b00000000, 0b00000000, 0b00000000, 0b00000000, 0b00000000,
  0b00000001, 0b10000000, 0b00000001, 0b11111111, 0b11111110, 0b10000000, 0b00000000, 0b00000000, 0b00000000, 0b00000000,
  0b00000011, 0b00000000, 0b00000001, 0b11111111, 0b11111111, 0b01000000, 0b00000000, 0b00000000, 0b00000000, 0b00000000,
  0b00000010, 0b00000000, 0b00000001, 0b11111111, 0b11111111, 0b01000000, 0b00000000, 0b00000000, 0b00000000, 0b00000000,
  0b00000100, 0b00000000, 0b00000001, 0b11111111, 0b11111111, 0b10100000, 0b00000000, 0b00000000, 0b00000000, 0b00000000,
  0b00001000, 0b00000000, 0b00000001, 0b11111111, 0b11111111, 0b11010000, 0b00000000, 0b00000000, 0b00000000, 0b00000000,
  0b00001000, 0b00000000, 0b00000001, 0b11111111, 0b11111111, 0b11010000, 0b00000000, 0b00000000, 0b00000000, 0b00000000,
  0b00010000, 0b00000000, 0b00000001, 0b11111111, 0b11111111, 0b11101000, 0b00000000, 0b00000000, 0b00000000, 0b00000000,
  0b00010000, 0b00000000, 0b00000001, 0b11111111, 0b11111111, 0b11101000, 0b00000000, 0b00000000, 0b00000000, 0b00000000,
  0b00100000, 0b00000000, 0b00000001, 0b11111111, 0b11111111, 0b11110100, 0b00000000, 0b00000000, 0b00000000, 0b00000000,
  0b00100000, 0b00000000, 0b00000001, 0b11111111, 0b11111111, 0b11110100, 0b00000000, 0b00000000, 0b00000000, 0b00000000,
  0b00100000, 0b00000000, 0b00000001, 0b11111111, 0b11111111, 0b11110100, 0b00000000, 0b00000000, 0b00000000, 0b00000000,
  0b01000000, 0b00000000, 0b00000001, 0b11111111, 0b11111111, 0b11111010, 0b00000000, 0b00000000, 0b00000000, 0b00000000,
  0b01000000, 0b00000000, 0b00000001, 0b11111111, 0b11111111, 0b11111010, 0b00000000, 0b00000000, 0b00000000, 0b00000000,
  0b01000000, 0b00000000, 0b00000001, 0b11111111, 0b11111111, 0b11111010, 0b00000000, 0b00000000, 0b00000000, 0b00000000,
  0b01000000, 0b00000000, 0b00000001, 0b11111111, 0b11111111, 0b11111010, 0b00000000, 0b00000000, 0b00000000, 0b00000000,
  0b01000000, 0b00011000, 0b01100001, 0b11111110, 0b00111111, 0b11111010, 0b00000000, 0b00000000, 0b00000000, 0b00000000,
  0b01000000, 0b00001100, 0b11000001, 0b11111101, 0b11011111, 0b11111010, 0b00000000, 0b00000000, 0b00000000, 0b00000000,
  0b01000000, 0b00000111, 0b10000001, 0b11111011, 0b11101111, 0b11111010, 0b00000000, 0b00000000, 0b00000000, 0b00000000,
  0b01000000, 0b00000011, 0b00000001, 0b11111011, 0b11101111, 0b11111010, 0b00000000, 0b00000000, 0b00000000, 0b00000000,
  0b01000000, 0b00000111, 0b10000001, 0b11111011, 0b11101111, 0b11111010, 0b00000000, 0b00000000, 0b00000000, 0b00000000,
  0b01100000, 0b00001100, 0b11000001, 0b11111101, 0b11011111, 0b11111010, 0b00000000, 0b00000000, 0b00000000, 0b00000000,
  0b00100000, 0b00011000, 0b01100001, 0b11111110, 0b00111111, 0b11111010, 0b00000000, 0b00000000, 0b00000000, 0b00000000,
  0b00100000, 0b00000000, 0b00000001, 0b11111111, 0b11111111, 0b11110100, 0b00000000, 0b00000000, 0b00000000, 0b00000000,
  0b00110000, 0b00000000, 0b00000001, 0b11111111, 0b11111111, 0b11110100, 0b00000000, 0b00000000, 0b00000000, 0b00000000,
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
};

const unsigned char PROGMEM frame2[] = {
  0b00000000, 0b00000000, 0b00000000, 0b00000000, 0b00000000, 0b00000000, 0b00000000, 0b00000000, 0b00000000, 0b00000000,
  0b00000000, 0b00000000, 0b00000011, 0b11000000, 0b00000000, 0b00000000, 0b00000000, 0b00000000, 0b00000000, 0b00000000,
  0b00000000, 0b00000000, 0b00000010, 0b01000000, 0b00000000, 0b00000000, 0b00000000, 0b00000000, 0b00000000, 0b00000000,
  0b00000000, 0b00000000, 0b00000110, 0b10100000, 0b00000000, 0b00000000, 0b00000000, 0b00000000, 0b00000000, 0b00000000,
  0b00000000, 0b00000000, 0b00000101, 0b10100000, 0b00000000, 0b00000000, 0b00000000, 0b00000000, 0b00000000, 0b00000000,
  0b00000000, 0b00000000, 0b00001101, 0b10010000, 0b00000000, 0b00000000, 0b00000000, 0b00000000, 0b00000000, 0b00000000,
  0b00000000, 0b00000000, 0b00001001, 0b11010000, 0b00000000, 0b00000000, 0b00000000, 0b00000000, 0b00000000, 0b00000000,
  0b00000000, 0b00000000, 0b00011001, 0b11101000, 0b00000000, 0b00000000, 0b00000000, 0b00000000, 0b00000000, 0b00000000,
  0b00000000, 0b00000000, 0b00010001, 0b11101000, 0b00000000, 0b00000000, 0b00000000, 0b00000000, 0b00000000, 0b00000000,
  0b00000000, 0b00000000, 0b00110001, 0b11110100, 0b00000000, 0b00000000, 0b00000000, 0b00000000, 0b00000000, 0b00000000,
  0b00000000, 0b00000000, 0b01100001, 0b11110010, 0b00000000, 0b00000000, 0b00000000, 0b00000000, 0b00000000, 0b00000000,
  0b00000000, 0b00000001, 0b11000001, 0b11111101, 0b10000000, 0b00000000, 0b00000000, 0b00000000, 0b00000000, 0b00000000,
  0b00000000, 0b00001111, 0b00000001, 0b11111100, 0b01110000, 0b00000000, 0b00000000, 0b00000000, 0b00000000, 0b00000000,
  0b00000000, 0b00011000, 0b00000001, 0b11111111, 0b10001000, 0b00000000, 0b00000000, 0b00000000, 0b00000000, 0b00000000,
  0b00000000, 0b01100000, 0b00000001, 0b11111111, 0b11110110, 0b00000000, 0b00000000, 0b00000000, 0b00000000, 0b00000000,
  0b00000000, 0b11000000, 0b00000001, 0b11111111, 0b11111001, 0b00000000, 0b00000000, 0b00000000, 0b00000000, 0b00000000,
  0b00000001, 0b10000000, 0b00000001, 0b11111111, 0b11111110, 0b10000000, 0b00000000, 0b00000000, 0b00000000, 0b00000000,
  0b00000011, 0b00000000, 0b00000001, 0b11111111, 0b11111111, 0b01000000, 0b00000000, 0b00000000, 0b00000000, 0b00000000,
  0b00000010, 0b00000000, 0b00000001, 0b11111111, 0b11111111, 0b01000000, 0b00000000, 0b00000000, 0b00000000, 0b00000000,
  0b00000100, 0b00000000, 0b00000001, 0b11111111, 0b11111111, 0b10100000, 0b00000000, 0b00000000, 0b00000000, 0b00000000,
  0b00001000, 0b00000000, 0b00000001, 0b11111111, 0b11111111, 0b11010000, 0b00000000, 0b00000000, 0b00000000, 0b00000000,
  0b00001000, 0b00000000, 0b00000001, 0b11111111, 0b11111111, 0b11010000, 0b00000000, 0b00000000, 0b00000000, 0b00000000,
  0b00010000, 0b00000000, 0b00000001, 0b11111111, 0b11111111, 0b11101000, 0b00000000, 0b00000000, 0b00000000, 0b00000000,
  0b00010000, 0b00000000, 0b00000001, 0b11111111, 0b11111111, 0b11101000, 0b00000000, 0b00000000, 0b00000000, 0b00000000,
  0b00100000, 0b00000000, 0b00000001, 0b11111111, 0b11111111, 0b11110100, 0b00000000, 0b00000000, 0b00000000, 0b00000000,
  0b00100000, 0b00000000, 0b00000001, 0b11111111, 0b11111111, 0b11110100, 0b00000000, 0b00000000, 0b00000000, 0b00000000,
  0b00100000, 0b00000000, 0b00000001, 0b11111111, 0b11111111, 0b11110100, 0b00000000, 0b00000000, 0b00000000, 0b00000000,
  0b01000000, 0b00000000, 0b00000001, 0b11111111, 0b11111111, 0b11111010, 0b00000000, 0b00000000, 0b00000000, 0b00000000,
  0b01000000, 0b00000000, 0b00000001, 0b11111111, 0b11111111, 0b11111010, 0b00000000, 0b00000000, 0b00000000, 0b00000000,
  0b01000000, 0b00000000, 0b00000001, 0b11111111, 0b11111111, 0b11111010, 0b00000000, 0b00000000, 0b00000000, 0b00000000,
  0b01000000, 0b00000000, 0b00000001, 0b11111111, 0b11111111, 0b11111010, 0b00000000, 0b00000000, 0b00000000, 0b00000000,
  0b01000000, 0b00011111, 0b11100001, 0b11111111, 0b11111111, 0b11111010, 0b00000000, 0b00000000, 0b00000000, 0b00000000,
  0b01000000, 0b00000000, 0b11000001, 0b11111111, 0b11111111, 0b11111010, 0b00000000, 0b00000000, 0b00000000, 0b00000000,
  0b01000000, 0b00000001, 0b10000001, 0b11111111, 0b11111111, 0b11111010, 0b00000000, 0b00000000, 0b00000000, 0b00000000,
  0b01000000, 0b00000011, 0b00000001, 0b11110000, 0b00001111, 0b11111010, 0b00000000, 0b00000000, 0b00000000, 0b00000000,
  0b01000000, 0b00000110, 0b00000001, 0b11111111, 0b11111111, 0b11111010, 0b00000000, 0b00000000, 0b00000000, 0b00000000,
  0b01100000, 0b00001100, 0b00000001, 0b11111111, 0b11111111, 0b11111010, 0b00000000, 0b00000000, 0b00000000, 0b00000000,
  0b00100000, 0b00011111, 0b11100001, 0b11111111, 0b11111111, 0b11111010, 0b00000000, 0b00000000, 0b00000000, 0b00000000,
  0b00100000, 0b00000000, 0b00000001, 0b11111111, 0b11111111, 0b11110100, 0b00000000, 0b00000000, 0b00000000, 0b00000000,
  0b00110000, 0b00000000, 0b00000001, 0b11111111, 0b11111111, 0b11110100, 0b00000000, 0b00000000, 0b00000000, 0b00000000,
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
};
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
void loop() {
  checkButtons();       // 1. Read input
  updatePet();          // 2. Update state over time
  handleScreenLogic();  // 3. Process actions
  render();             // 4. Display results
  delay(100);           // 5. Short pause
}

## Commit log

2026-06-21 Update BOM.csv
    done for now?
    [BOM.csv]
2026-06-21 Update BOM.csv
    fixed
    [BOM.csv]
2026-06-21 Changed folders
    [BTtamagotchi-B_Cu.gbr, BTtamagotchi-B_Mask.gbr, BTtamagotchi-B_Paste.gbr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]
2026-06-21 FINAL COMMIT
    [ARIRANG FINAL.f3d, ARIRANG.step, BTtamagotchi.kicad_pcb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]
2026-06-21 file names and readme changes
    [ARIRANG-B_Cu.gbr, ARIRANG-B_Mask.gbr, ARIRANG-B_Paste.gbr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]
